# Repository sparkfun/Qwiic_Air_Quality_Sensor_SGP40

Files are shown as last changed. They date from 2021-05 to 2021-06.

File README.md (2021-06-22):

SparkFun Air Quality Sensor Breakout - SGP40 (Qwiic)
========================================

SparkFun Air Quality Sensor Breakout - SGP40 (Qwiic) (SEN-18345) (https://www.sparkfun.com/products/18345)

[*SparkFun Air Quality Sensor Breakout - SGP40 (Qwiic) (SEN-18345)*](https://www.sparkfun.com/products/18345)

The SGP40 is a digital gas sensor designed for easy integration into air purifiers or demand-controlled ventilation systems.
Sensirion’s CMOSens® technology offers a complete, easy to use sensor system on a single chip featuring a digital
I<sup>2</sup>C interface and a temperature controlled micro hotplate, providing a humidity compensated VOC based indoor air quality signal.
The output signal can be directly processed by Sensirion’s powerful VOC Algorithm to translate the raw signal into a VOC Index as a robust
measure for indoor air quality. The VOC Algorithm automatically adapts to the environment the sensor is exposed to. Both sensing element and
VOC Algorithm feature an unmatched robustness against contaminating gases present in real world applications enabling a unique long term
stability as well as low drift and device to device variation.

Repository Contents
-------------------
* **/Documents** - datasheets etc.
* **/Hardware** - Eagle design files (.brd, .sch)

Documentation
--------------
* **[SGP40 Arduino Library](https://github.com/sparkfun/SparkFun_SGP40_Arduino_Library)** - Arduino library for the SparkFun Air Quality Sensor - SGP40.
* **[Hookup Guide](https://learn.sparkfun.com/tutorials/air-quality-sensor---sgp40-qwiic-hookup-guide)** - Basic hookup guide for the SparkFun Air Quality Sensor - SGP40.

Product Versions
----------------
* [SEN-18345](https://www.sparkfun.com/products/18345) - Initial SparkFun release.
* [SPX-17729](https://www.sparkfun.com/products/17729) - Original SparkX Release.

License Information
-------------------

This product is _**open source**_!

Please review the LICENSE.md file for license information.

If you have any questions or concerns on licensing, please contact technical support on our [SparkFun forums](https://forum.sparkfun.com/viewforum.php?f=152).

Distributed as-is; no warranty is given.

- Your friends at SparkFun.

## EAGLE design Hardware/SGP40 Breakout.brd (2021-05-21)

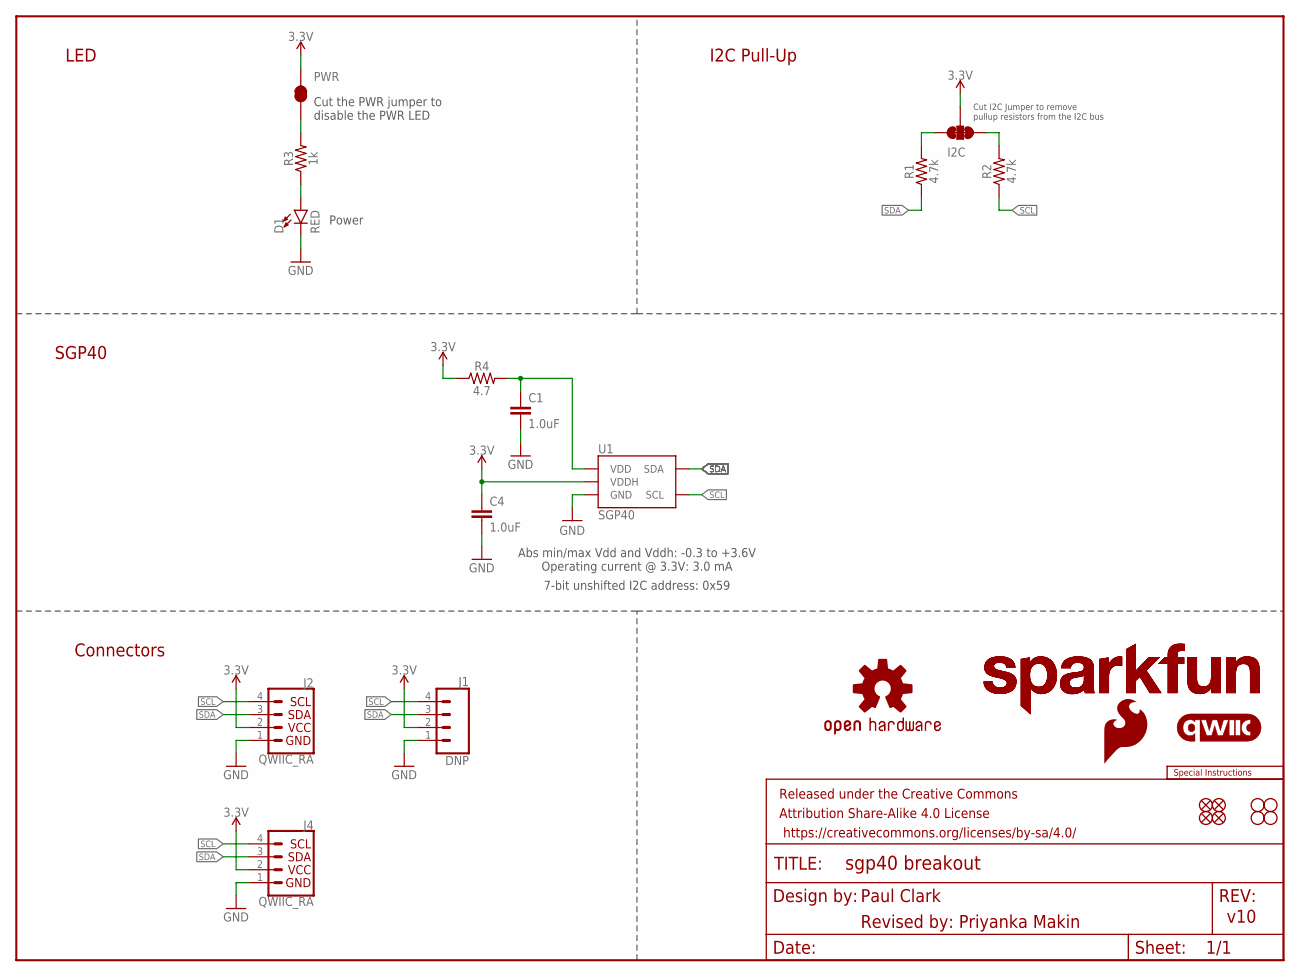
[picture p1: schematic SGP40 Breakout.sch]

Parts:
C1, C4: 1.0uF; 0603
D1: RED; LED-0603
FRAME1: FRAME-LETTER; CREATIVE_COMMONS
I2C: JUMPER-SMT_3_2-NC_TRACE_SILK; SMT-JUMPER_3_2-NC_TRACE_SILK
J1: DNP; 1X04_NO_SILK
J2, J4: QWIIC_RA; JST04_1MM_RA
JP1, JP2, JP5, JP6: FIDUCIAL0.2MM; FIDUCIAL-0.2MM
JP3, JP4, JP7, JP8: STAND-OFF
LOGO1: SPECIAL_INSTRUCTIONS-ORDERING; ORDERING_INSTRUCTIONS
LOGO2: QWIIC_LOGO_5MM; QWIIC_5MM
LOGO3, LOGO6: SFE_LOGO_NAME.1_INCH; SFE_LOGO_NAME_.1
LOGO4: SFE_LOGO_FLAME.1_INCH; SFE_LOGO_FLAME_.1
LOGO5: OSHW-LOGOS; OSHW-LOGO-S
PWR: JUMPER-SMT_2_NC_TRACE_SILK; SMT-JUMPER_2_NC_TRACE_SILK
R1, R2: 4.7k; 0603
R3: 1k; 0603
R4: 4.7; 0603
U1: SGP40

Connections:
3.3V: C4.1, I2C.2, J1.2, J2.2, J4.2, PWR.2, R4.1, U1.5 (VDDH)
GND: C1.2, C4.2, D1.C, J1.1, J2.1, J4.1, U1.2 (GND), U1.4 (GND), U1.DIEPAD (GND)
unnamed: PWR.1, R3.2
unnamed: I2C.3, R1.2
unnamed: D1.A, R3.1
unnamed: I2C.1, R2.2
unnamed: C1.1, R4.2, U1.1 (VDD)
SCL: J1.4, J2.4, J4.4, R2.1, U1.6 (SCL)
SDA: J1.3, J2.3, J4.3, R1.1, U1.3 (SDA)

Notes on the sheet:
Paul Clark
v10
7-bit unshifted I2C address: 0x59
Power
I2C Pull-Up
SGP40
Connectors
Cut the PWR jumper to disable the PWR LED
Cut I2C Jumper to remove pullup resistors from the I2C bus
LED
Revised by: Priyanka Makin
Abs min/max Vdd and Vddh: -0.3 to +3.6V Operating current @ 3.3V: 3.0 mA

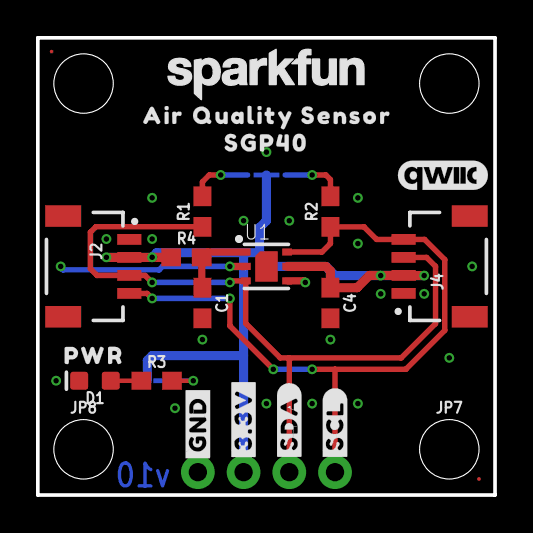
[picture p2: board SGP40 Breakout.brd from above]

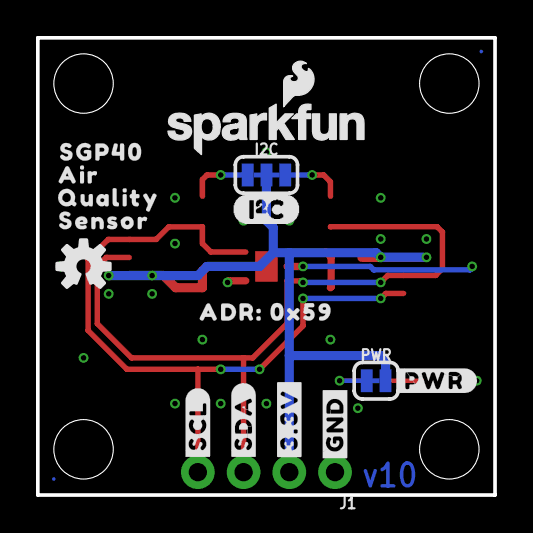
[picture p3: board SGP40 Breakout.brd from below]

Board: 2 copper layers, 25.4 x 25.4 mm, 48 parts (19 on the bottom side), 9 nets.

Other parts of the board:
U$1, U$33: #GND#0
U$2, U$34: #3#3V#0
U$3, U$35: #SDA#0
U$4, U$36: #SCL#0
U$5: PWR0
U$6: #PWR#0
U$15: I2C
U$19, U$20: SGP400
U$23, U$24: AIR0
U$25, U$28: QUALITY0
U$29, U$30: SENSOR0
U$31: ADR#_0X590

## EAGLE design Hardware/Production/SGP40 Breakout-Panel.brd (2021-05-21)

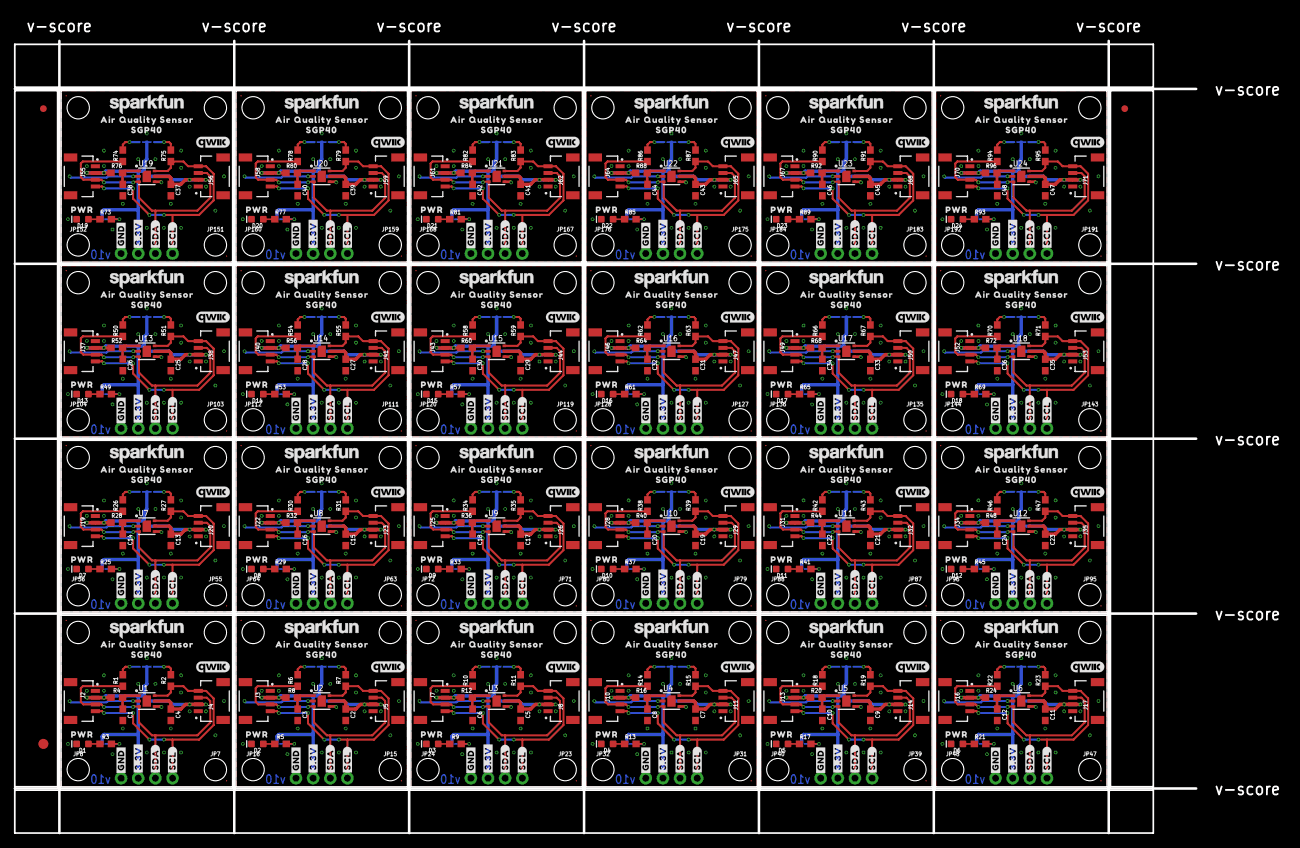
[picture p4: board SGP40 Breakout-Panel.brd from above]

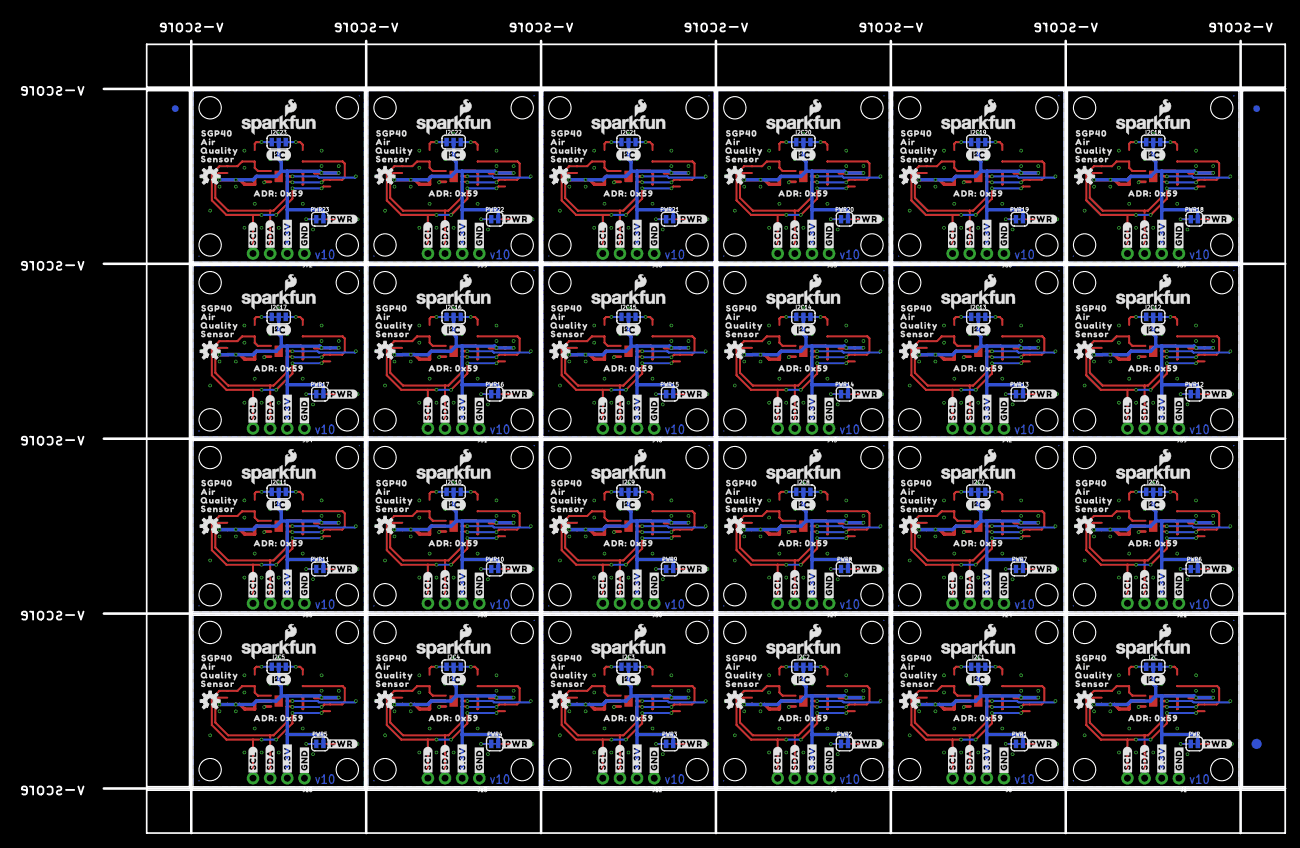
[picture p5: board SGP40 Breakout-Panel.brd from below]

Board: 2 copper layers, 175.0 x 117.3 mm, 1110 parts (459 on the bottom side), 216 nets.

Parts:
C1, C2, C3, C4, C5, C6, C7, C8, C9, C10, C11, C12, C13, C14, C15, C16, C17, C18, C19, C20, C21, C22, C23, C24, C25, C26, C27, C28, C29, C30, C31, C32, C33, C34, C35, C36, C37, C38, C39, C40, C41, C42, C43, C44, C45, C46, C47, C48: 1.0uF; 0603
D1, D2, D3, D4, D5, D6, D7, D8, D9, D10, D11, D12, D13, D14, D15, D16, D17, D18, D19, D20, D21, D22, D23, D24: RED; LED-0603
E$1, E$2, E$3, E$4: FIDUCIAL-1X2
E$5, E$6: FIDUCIAL-1.5X3
I2C, I2C1, I2C2, I2C3, I2C4, I2C5, I2C6, I2C7, I2C8, I2C9, I2C10, I2C11, I2C12, I2C13, I2C14, I2C15, I2C16, I2C17, I2C18, I2C19, I2C20, I2C21, I2C22, I2C23: JUMPER-SMT_3_2-NC_TRACE_SILK; SMT-JUMPER_3_2-NC_TRACE_SILK
J1, J6, J9, J12, J15, J18, J21, J24, J27, J30, J33, J36, J39, J42, J45, J48, J51, J54, J57, J60, J63, J66, J69, J72: DNP; 1X04_NO_SILK
J2, J3, J4, J5, J7, J8, J10, J11, J13, J14, J16, J17, J19, J20, J22, J23, J25, J26, J28, J29, J31, J32, J34, J35, J37, J38, J40, J41, J43, J44, J46, J47, J49, J50, J52, J53, J55, J56, J58, J59, J61, J62, J64, J65, J67, J68, J70, J71: QWIIC_RA; JST04_1MM_RA
JP1, JP2, JP5, JP6, JP11, JP12, JP13, JP14, JP19, JP20, JP21, JP22, JP27, JP28, JP29, JP30, JP35, JP36, JP37, JP38, JP43, JP44, JP45, JP46, JP51, JP52, JP53, JP54, JP59, JP60, JP61, JP62, JP67, JP68, JP69, JP70, JP75, JP76, JP77, JP78, JP83, JP84, JP85, JP86, JP91, JP92, JP93, JP94, JP99, JP100, JP101, JP102, JP107, JP108, JP109, JP110, JP115, JP116, JP117, JP118, JP123, JP124, JP125, JP126, JP131, JP132, JP133, JP134, JP139, JP140, JP141, JP142, JP147, JP148, JP149, JP150, JP155, JP156, JP157, JP158, JP163, JP164, JP165, JP166, JP171, JP172, JP173, JP174, JP179, JP180, JP181, JP182, JP187, JP188, JP189, JP190: FIDUCIAL0.2MM; FIDUCIAL-0.2MM
JP3, JP4, JP7, JP8, JP9, JP10, JP15, JP16, JP17, JP18, JP23, JP24, JP25, JP26, JP31, JP32, JP33, JP34, JP39, JP40, JP41, JP42, JP47, JP48, JP49, JP50, JP55, JP56, JP57, JP58, JP63, JP64, JP65, JP66, JP71, JP72, JP73, JP74, JP79, JP80, JP81, JP82, JP87, JP88, JP89, JP90, JP95, JP96, JP97, JP98, JP103, JP104, JP105, JP106, JP111, JP112, JP113, JP114, JP119, JP120, JP121, JP122, JP127, JP128, JP129, JP130, JP135, JP136, JP137, JP138, JP143, JP144, JP145, JP146, JP151, JP152, JP153, JP154, JP159, JP160, JP161, JP162, JP167, JP168, JP169, JP170, JP175, JP176, JP177, JP178, JP183, JP184, JP185, JP186, JP191, JP192: STAND-OFF
LOGO1, LOGO5, LOGO11, LOGO16, LOGO21, LOGO26, LOGO31, LOGO36, LOGO41, LOGO46, LOGO51, LOGO56, LOGO61, LOGO66, LOGO71, LOGO76, LOGO81, LOGO86, LOGO91, LOGO96, LOGO101, LOGO106, LOGO111, LOGO116: OSHW-LOGOS; OSHW-LOGO-S
LOGO2, LOGO7, LOGO12, LOGO17, LOGO22, LOGO27, LOGO32, LOGO37, LOGO42, LOGO47, LOGO52, LOGO57, LOGO62, LOGO67, LOGO72, LOGO77, LOGO82, LOGO87, LOGO92, LOGO97, LOGO102, LOGO107, LOGO112, LOGO117: QWIIC_LOGO_5MM; QWIIC_5MM
LOGO3, LOGO6, LOGO8, LOGO10, LOGO13, LOGO15, LOGO18, LOGO20, LOGO23, LOGO25, LOGO28, LOGO30, LOGO33, LOGO35, LOGO38, LOGO40, LOGO43, LOGO45, LOGO48, LOGO50, LOGO53, LOGO55, LOGO58, LOGO60, LOGO63, LOGO65, LOGO68, LOGO70, LOGO73, LOGO75, LOGO78, LOGO80, LOGO83, LOGO85, LOGO88, LOGO90, LOGO93, LOGO95, LOGO98, LOGO100, LOGO103, LOGO105, LOGO108, LOGO110, LOGO113, LOGO115, LOGO118, LOGO120: SFE_LOGO_NAME.1_INCH; SFE_LOGO_NAME_.1
LOGO4, LOGO9, LOGO14, LOGO19, LOGO24, LOGO29, LOGO34, LOGO39, LOGO44, LOGO49, LOGO54, LOGO59, LOGO64, LOGO69, LOGO74, LOGO79, LOGO84, LOGO89, LOGO94, LOGO99, LOGO104, LOGO109, LOGO114, LOGO119: SFE_LOGO_FLAME.1_INCH; SFE_LOGO_FLAME_.1
PWR, PWR1, PWR2, PWR3, PWR4, PWR5, PWR6, PWR7, PWR8, PWR9, PWR10, PWR11, PWR12, PWR13, PWR14, PWR15, PWR16, PWR17, PWR18, PWR19, PWR20, PWR21, PWR22, PWR23: JUMPER-SMT_2_NC_TRACE_SILK; SMT-JUMPER_2_NC_TRACE_SILK
R1, R2, R6, R7, R10, R11, R14, R15, R18, R19, R22, R23, R26, R27, R30, R31, R34, R35, R38, R39, R42, R43, R46, R47, R50, R51, R54, R55, R58, R59, R62, R63, R66, R67, R70, R71, R74, R75, R78, R79, R82, R83, R86, R87, R90, R91, R94, R95: 4.7k; 0603
R3, R5, R9, R13, R17, R21, R25, R29, R33, R37, R41, R45, R49, R53, R57, R61, R65, R69, R73, R77, R81, R85, R89, R93: 1k; 0603
R4, R8, R12, R16, R20, R24, R28, R32, R36, R40, R44, R48, R52, R56, R60, R64, R68, R72, R76, R80, R84, R88, R92, R96: 4.7; 0603
U1, U2, U3, U4, U5, U6, U7, U8, U9, U10, U11, U12, U13, U14, U15, U16, U17, U18, U19, U20, U21, U22, U23, U24: SGP40
U$1, U$18, U$27, U$33, U$51, U$55, U$71, U$75, U$91, U$95, U$111, U$115, U$131, U$135, U$151, U$155, U$171, U$175, U$191, U$195, U$211, U$215, U$231, U$235, U$251, U$255, U$271, U$275, U$291, U$295, U$311, U$315, U$331, U$335, U$351, U$355, U$371, U$375, U$391, U$395, U$411, U$415, U$431, U$435, U$451, U$455, U$471, U$475: #GND#0
U$2, U$21, U$32, U$34, U$52, U$56, U$72, U$76, U$92, U$96, U$112, U$116, U$132, U$136, U$152, U$156, U$172, U$176, U$192, U$196, U$212, U$216, U$232, U$236, U$252, U$256, U$272, U$276, U$292, U$296, U$312, U$316, U$332, U$336, U$352, U$356, U$372, U$376, U$392, U$396, U$412, U$416, U$432, U$436, U$452, U$456, U$472, U$476: #3#3V#0
U$3, U$22, U$35, U$37, U$53, U$57, U$73, U$77, U$93, U$97, U$113, U$117, U$133, U$137, U$153, U$157, U$173, U$177, U$193, U$197, U$213, U$217, U$233, U$237, U$253, U$257, U$273, U$277, U$293, U$297, U$313, U$317, U$333, U$337, U$353, U$357, U$373, U$377, U$393, U$397, U$413, U$417, U$433, U$437, U$453, U$457, U$473, U$477: #SDA#0
U$4, U$26, U$36, U$38, U$54, U$58, U$74, U$78, U$94, U$98, U$114, U$118, U$134, U$138, U$154, U$158, U$174, U$178, U$194, U$198, U$214, U$218, U$234, U$238, U$254, U$258, U$274, U$278, U$294, U$298, U$314, U$318, U$334, U$338, U$354, U$358, U$374, U$378, U$394, U$398, U$414, U$418, U$434, U$438, U$454, U$458, U$474, U$478: #SCL#0
U$5, U$39, U$59, U$79, U$99, U$119, U$139, U$159, U$179, U$199, U$219, U$239, U$259, U$279, U$299, U$319, U$339, U$359, U$379, U$399, U$419, U$439, U$459, U$479: PWR0
U$6, U$40, U$60, U$80, U$100, U$120, U$140, U$160, U$180, U$200, U$220, U$240, U$260, U$280, U$300, U$320, U$340, U$360, U$380, U$400, U$420, U$440, U$460, U$480: #PWR#0
U$7, U$15, U$41, U$61, U$81, U$101, U$121, U$141, U$161, U$181, U$201, U$221, U$241, U$261, U$281, U$301, U$321, U$341, U$361, U$381, U$401, U$421, U$441, U$461: I2C
U$8, U$9, U$19, U$20, U$42, U$43, U$62, U$63, U$82, U$83, U$102, U$103, U$122, U$123, U$142, U$143, U$162, U$163, U$182, U$183, U$202, U$203, U$222, U$223, U$242, U$243, U$262, U$263, U$282, U$283, U$302, U$303, U$322, U$323, U$342, U$343, U$362, U$363, U$382, U$383, U$402, U$403, U$422, U$423, U$442, U$443, U$462, U$463: SGP400
U$10, U$11, U$23, U$24, U$44, U$45, U$64, U$65, U$84, U$85, U$104, U$105, U$124, U$125, U$144, U$145, U$164, U$165, U$184, U$185, U$204, U$205, U$224, U$225, U$244, U$245, U$264, U$265, U$284, U$285, U$304, U$305, U$324, U$325, U$344, U$345, U$364, U$365, U$384, U$385, U$404, U$405, U$424, U$425, U$444, U$445, U$464, U$465: AIR0
U$12, U$13, U$25, U$28, U$46, U$47, U$66, U$67, U$86, U$87, U$106, U$107, U$126, U$127, U$146, U$147, U$166, U$167, U$186, U$187, U$206, U$207, U$226, U$227, U$246, U$247, U$266, U$267, U$286, U$287, U$306, U$307, U$326, U$327, U$346, U$347, U$366, U$367, U$386, U$387, U$406, U$407, U$426, U$427, U$446, U$447, U$466, U$467: QUALITY0
U$14, U$16, U$29, U$30, U$48, U$49, U$68, U$69, U$88, U$89, U$108, U$109, U$128, U$129, U$148, U$149, U$168, U$169, U$188, U$189, U$208, U$209, U$228, U$229, U$248, U$249, U$268, U$269, U$288, U$289, U$308, U$309, U$328, U$329, U$348, U$349, U$368, U$369, U$388, U$389, U$408, U$409, U$428, U$429, U$448, U$449, U$468, U$469: SENSOR0
U$17, U$31, U$50, U$70, U$90, U$110, U$130, U$150, U$170, U$190, U$210, U$230, U$250, U$270, U$290, U$310, U$330, U$350, U$370, U$390, U$410, U$430, U$450, U$470: ADR#_0X590

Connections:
3.3V: C4.1, I2C.2, J1.2, J2.2, J4.2, PWR.2, R4.1, U1.5
3.3V1: C2.1, I2C1.2, J3.2, J5.2, J6.2, PWR1.2, R8.1, U2.5
3.3V2: C5.1, I2C2.2, J7.2, J8.2, J9.2, PWR2.2, R12.1, U3.5
3.3V3: C7.1, I2C3.2, J10.2, J11.2, J12.2, PWR3.2, R16.1, U4.5
3.3V4: C9.1, I2C4.2, J13.2, J14.2, J15.2, PWR4.2, R20.1, U5.5
3.3V5: C11.1, I2C5.2, J16.2, J17.2, J18.2, PWR5.2, R24.1, U6.5
3.3V6: C13.1, I2C6.2, J19.2, J20.2, J21.2, PWR6.2, R28.1, U7.5
3.3V7: C15.1, I2C7.2, J22.2, J23.2, J24.2, PWR7.2, R32.1, U8.5
3.3V8: C17.1, I2C8.2, J25.2, J26.2, J27.2, PWR8.2, R36.1, U9.5
3.3V9: C19.1, I2C9.2, J28.2, J29.2, J30.2, PWR9.2, R40.1, U10.5
3.3V10: C21.1, I2C10.2, J31.2, J32.2, J33.2, PWR10.2, R44.1, U11.5
3.3V11: C23.1, I2C11.2, J34.2, J35.2, J36.2, PWR11.2, R48.1, U12.5
3.3V12: C25.1, I2C12.2, J37.2, J38.2, J39.2, PWR12.2, R52.1, U13.5
3.3V13: C27.1, I2C13.2, J40.2, J41.2, J42.2, PWR13.2, R56.1, U14.5
3.3V14: C29.1, I2C14.2, J43.2, J44.2, J45.2, PWR14.2, R60.1, U15.5
3.3V15: C31.1, I2C15.2, J46.2, J47.2, J48.2, PWR15.2, R64.1, U16.5
3.3V16: C33.1, I2C16.2, J49.2, J50.2, J51.2, PWR16.2, R68.1, U17.5
3.3V17: C35.1, I2C17.2, J52.2, J53.2, J54.2, PWR17.2, R72.1, U18.5
3.3V18: C37.1, I2C18.2, J55.2, J56.2, J57.2, PWR18.2, R76.1, U19.5
3.3V19: C39.1, I2C19.2, J58.2, J59.2, J60.2, PWR19.2, R80.1, U20.5
3.3V20: C41.1, I2C20.2, J61.2, J62.2, J63.2, PWR20.2, R84.1, U21.5
3.3V21: C43.1, I2C21.2, J64.2, J65.2, J66.2, PWR21.2, R88.1, U22.5
3.3V22: C45.1, I2C22.2, J67.2, J68.2, J69.2, PWR22.2, R92.1, U23.5
3.3V23: C47.1, I2C23.2, J70.2, J71.2, J72.2, PWR23.2, R96.1, U24.5
GND: C1.2, C4.2, D1.C, J1.1, J2.1, J4.1, U1.2, U1.4, U1.DIEPAD
GND1: C2.2, C3.2, D2.C, J3.1, J5.1, J6.1, U2.2, U2.4, U2.DIEPAD
GND2: C5.2, C6.2, D3.C, J7.1, J8.1, J9.1, U3.2, U3.4, U3.DIEPAD
GND3: C7.2, C8.2, D4.C, J10.1, J11.1, J12.1, U4.2, U4.4, U4.DIEPAD
GND4: C9.2, C10.2, D5.C, J13.1, J14.1, J15.1, U5.2, U5.4, U5.DIEPAD
GND5: C11.2, C12.2, D6.C, J16.1, J17.1, J18.1, U6.2, U6.4, U6.DIEPAD
GND6: C13.2, C14.2, D7.C, J19.1, J20.1, J21.1, U7.2, U7.4, U7.DIEPAD
GND7: C15.2, C16.2, D8.C, J22.1, J23.1, J24.1, U8.2, U8.4, U8.DIEPAD
GND8: C17.2, C18.2, D9.C, J25.1, J26.1, J27.1, U9.2, U9.4, U9.DIEPAD
GND9: C19.2, C20.2, D10.C, J28.1, J29.1, J30.1, U10.2, U10.4, U10.DIEPAD
GND10: C21.2, C22.2, D11.C, J31.1, J32.1, J33.1, U11.2, U11.4, U11.DIEPAD
GND11: C23.2, C24.2, D12.C, J34.1, J35.1, J36.1, U12.2, U12.4, U12.DIEPAD
GND12: C25.2, C26.2, D13.C, J37.1, J38.1, J39.1, U13.2, U13.4, U13.DIEPAD
GND13: C27.2, C28.2, D14.C, J40.1, J41.1, J42.1, U14.2, U14.4, U14.DIEPAD
GND14: C29.2, C30.2, D15.C, J43.1, J44.1, J45.1, U15.2, U15.4, U15.DIEPAD
GND15: C31.2, C32.2, D16.C, J46.1, J47.1, J48.1, U16.2, U16.4, U16.DIEPAD
GND16: C33.2, C34.2, D17.C, J49.1, J50.1, J51.1, U17.2, U17.4, U17.DIEPAD
GND17: C35.2, C36.2, D18.C, J52.1, J53.1, J54.1, U18.2, U18.4, U18.DIEPAD
GND18: C37.2, C38.2, D19.C, J55.1, J56.1, J57.1, U19.2, U19.4, U19.DIEPAD
GND19: C39.2, C40.2, D20.C, J58.1, J59.1, J60.1, U20.2, U20.4, U20.DIEPAD
GND20: C41.2, C42.2, D21.C, J61.1, J62.1, J63.1, U21.2, U21.4, U21.DIEPAD
GND21: C43.2, C44.2, D22.C, J64.1, J65.1, J66.1, U22.2, U22.4, U22.DIEPAD
GND22: C45.2, C46.2, D23.C, J67.1, J68.1, J69.1, U23.2, U23.4, U23.DIEPAD
GND23: C47.2, C48.2, D24.C, J70.1, J71.1, J72.1, U24.2, U24.4, U24.DIEPAD
unnamed: PWR.1, R3.2
unnamed: I2C.3, R1.2
unnamed: D1.A, R3.1
unnamed: I2C.1, R2.2
unnamed: C1.1, R4.2, U1.1
unnamed: D2.A, R5.1
unnamed: PWR1.1, R5.2
unnamed: I2C1.3, R6.2
unnamed: I2C1.1, R7.2
unnamed: C3.1, R8.2, U2.1
unnamed: D3.A, R9.1
unnamed: PWR2.1, R9.2
unnamed: I2C2.3, R10.2
unnamed: I2C2.1, R11.2
unnamed: C6.1, R12.2, U3.1
unnamed: D4.A, R13.1
unnamed: PWR3.1, R13.2
unnamed: I2C3.3, R14.2
unnamed: I2C3.1, R15.2
unnamed: C8.1, R16.2, U4.1
unnamed: D5.A, R17.1
unnamed: PWR4.1, R17.2
unnamed: I2C4.3, R18.2
unnamed: I2C4.1, R19.2
unnamed: C10.1, R20.2, U5.1
unnamed: D6.A, R21.1
unnamed: PWR5.1, R21.2
unnamed: I2C5.3, R22.2
unnamed: I2C5.1, R23.2
unnamed: C12.1, R24.2, U6.1
unnamed: D7.A, R25.1
unnamed: PWR6.1, R25.2
unnamed: I2C6.3, R26.2
unnamed: I2C6.1, R27.2
unnamed: C14.1, R28.2, U7.1
unnamed: D8.A, R29.1
unnamed: PWR7.1, R29.2
unnamed: I2C7.3, R30.2
unnamed: I2C7.1, R31.2
unnamed: C16.1, R32.2, U8.1
unnamed: D9.A, R33.1
unnamed: PWR8.1, R33.2
unnamed: I2C8.3, R34.2
unnamed: I2C8.1, R35.2
unnamed: C18.1, R36.2, U9.1
unnamed: D10.A, R37.1
unnamed: PWR9.1, R37.2
unnamed: I2C9.3, R38.2
unnamed: I2C9.1, R39.2
unnamed: C20.1, R40.2, U10.1
unnamed: D11.A, R41.1
unnamed: PWR10.1, R41.2
unnamed: I2C10.3, R42.2
unnamed: I2C10.1, R43.2
unnamed: C22.1, R44.2, U11.1
unnamed: D12.A, R45.1
unnamed: PWR11.1, R45.2
unnamed: I2C11.3, R46.2
unnamed: I2C11.1, R47.2
unnamed: C24.1, R48.2, U12.1
unnamed: D13.A, R49.1
unnamed: PWR12.1, R49.2
unnamed: I2C12.3, R50.2
unnamed: I2C12.1, R51.2
unnamed: C26.1, R52.2, U13.1
unnamed: D14.A, R53.1
unnamed: PWR13.1, R53.2
unnamed: I2C13.3, R54.2
unnamed: I2C13.1, R55.2
unnamed: C28.1, R56.2, U14.1
unnamed: D15.A, R57.1
unnamed: PWR14.1, R57.2
unnamed: I2C14.3, R58.2
unnamed: I2C14.1, R59.2
unnamed: C30.1, R60.2, U15.1
unnamed: D16.A, R61.1
unnamed: PWR15.1, R61.2
unnamed: I2C15.3, R62.2
unnamed: I2C15.1, R63.2
unnamed: C32.1, R64.2, U16.1
unnamed: D17.A, R65.1
unnamed: PWR16.1, R65.2
unnamed: I2C16.3, R66.2
unnamed: I2C16.1, R67.2
unnamed: C34.1, R68.2, U17.1
unnamed: D18.A, R69.1
unnamed: PWR17.1, R69.2
unnamed: I2C17.3, R70.2
unnamed: I2C17.1, R71.2
unnamed: C36.1, R72.2, U18.1
unnamed: D19.A, R73.1
unnamed: PWR18.1, R73.2
unnamed: I2C18.3, R74.2
unnamed: I2C18.1, R75.2
unnamed: C38.1, R76.2, U19.1
unnamed: D20.A, R77.1
unnamed: PWR19.1, R77.2
unnamed: I2C19.3, R78.2
unnamed: I2C19.1, R79.2
unnamed: C40.1, R80.2, U20.1
unnamed: D21.A, R81.1
unnamed: PWR20.1, R81.2
unnamed: I2C20.3, R82.2
unnamed: I2C20.1, R83.2
unnamed: C42.1, R84.2, U21.1
unnamed: D22.A, R85.1
unnamed: PWR21.1, R85.2
unnamed: I2C21.3, R86.2
unnamed: I2C21.1, R87.2
unnamed: C44.1, R88.2, U22.1
unnamed: D23.A, R89.1
unnamed: PWR22.1, R89.2
unnamed: I2C22.3, R90.2
unnamed: I2C22.1, R91.2
unnamed: C46.1, R92.2, U23.1
unnamed: D24.A, R93.1
unnamed: PWR23.1, R93.2
unnamed: I2C23.3, R94.2
unnamed: I2C23.1, R95.2
unnamed: C48.1, R96.2, U24.1
SCL: J1.4, J2.4, J4.4, R2.1, U1.6
SCL1: J3.4, J5.4, J6.4, R7.1, U2.6
SCL2: J7.4, J8.4, J9.4, R11.1, U3.6
SCL3: J10.4, J11.4, J12.4, R15.1, U4.6
SCL4: J13.4, J14.4, J15.4, R19.1, U5.6
SCL5: J16.4, J17.4, J18.4, R23.1, U6.6
SCL6: J19.4, J20.4, J21.4, R27.1, U7.6
SCL7: J22.4, J23.4, J24.4, R31.1, U8.6
SCL8: J25.4, J26.4, J27.4, R35.1, U9.6
SCL9: J28.4, J29.4, J30.4, R39.1, U10.6
SCL10: J31.4, J32.4, J33.4, R43.1, U11.6
SCL11: J34.4, J35.4, J36.4, R47.1, U12.6
SCL12: J37.4, J38.4, J39.4, R51.1, U13.6
SCL13: J40.4, J41.4, J42.4, R55.1, U14.6
SCL14: J43.4, J44.4, J45.4, R59.1, U15.6
SCL15: J46.4, J47.4, J48.4, R63.1, U16.6
SCL16: J49.4, J50.4, J51.4, R67.1, U17.6
SCL17: J52.4, J53.4, J54.4, R71.1, U18.6
SCL18: J55.4, J56.4, J57.4, R75.1, U19.6
SCL19: J58.4, J59.4, J60.4, R79.1, U20.6
SCL20: J61.4, J62.4, J63.4, R83.1, U21.6
SCL21: J64.4, J65.4, J66.4, R87.1, U22.6
SCL22: J67.4, J68.4, J69.4, R91.1, U23.6
SCL23: J70.4, J71.4, J72.4, R95.1, U24.6
SDA: J1.3, J2.3, J4.3, R1.1, U1.3
SDA1: J3.3, J5.3, J6.3, R6.1, U2.3
SDA2: J7.3, J8.3, J9.3, R10.1, U3.3
SDA3: J10.3, J11.3, J12.3, R14.1, U4.3
SDA4: J13.3, J14.3, J15.3, R18.1, U5.3
SDA5: J16.3, J17.3, J18.3, R22.1, U6.3
SDA6: J19.3, J20.3, J21.3, R26.1, U7.3
SDA7: J22.3, J23.3, J24.3, R30.1, U8.3
SDA8: J25.3, J26.3, J27.3, R34.1, U9.3
SDA9: J28.3, J29.3, J30.3, R38.1, U10.3
SDA10: J31.3, J32.3, J33.3, R42.1, U11.3
SDA11: J34.3, J35.3, J36.3, R46.1, U12.3
SDA12: J37.3, J38.3, J39.3, R50.1, U13.3
SDA13: J40.3, J41.3, J42.3, R54.1, U14.3
SDA14: J43.3, J44.3, J45.3, R58.1, U15.3
SDA15: J46.3, J47.3, J48.3, R62.1, U16.3
SDA16: J49.3, J50.3, J51.3, R66.1, U17.3
SDA17: J52.3, J53.3, J54.3, R70.1, U18.3
SDA18: J55.3, J56.3, J57.3, R74.1, U19.3
SDA19: J58.3, J59.3, J60.3, R78.1, U20.3
SDA20: J61.3, J62.3, J63.3, R82.1, U21.3
SDA21: J64.3, J65.3, J66.3, R86.1, U22.3
SDA22: J67.3, J68.3, J69.3, R90.1, U23.3
SDA23: J70.3, J71.3, J72.3, R94.1, U24.3

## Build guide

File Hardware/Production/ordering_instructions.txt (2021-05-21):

panel size, 169x117mm
PCB thickness, 1.6mm
number of layers, 2
soldermask color, Red
silkscreen color, White
oz copper, 1oz
finish, HASL lead free
stencils, top
pcs per panel, 24
min trace width, 0.2540mm / 0.0100in
min drill size, 0.3000mm / 0.0118in

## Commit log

2021-05-12 Initial commit with SparkX design files, readme, and datasheets
    [SGP40 Breakout.brd, SGP40 Breakout.sch]
2021-05-17 Update logos on board
    [SGP40 Breakout.brd, SGP40 Breakout.sch]
2021-05-18 Petes updates:
    Update version number in sch
    Added 2 more standoffs (moved power LED and jumper)
    Update value of qwiic connector in schematic
    Update legacy vector font
    Add qwiic connector and header measure
    Switched I2C pullup resistors to 4.7k
    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
    [SGP40 Breakout.brd, SGP40 Breakout.sch]
2021-05-18 Update silk
    LED label plain text
    Inverted bubbled for LED jumper
    Make SDA/SCL pin labels square on one side
    [SGP40 Breakout.brd]
2021-05-19 Design review updates
    SDA, SCL buzzard placement
    3.3V trace → 20
    Add operating current to sch
    [SGP40 Breakout.brd, SGP40 Breakout.sch]
2021-05-21 QC Double-check
    [SGP40 Breakout.brd, SGP40 Breakout.sch]

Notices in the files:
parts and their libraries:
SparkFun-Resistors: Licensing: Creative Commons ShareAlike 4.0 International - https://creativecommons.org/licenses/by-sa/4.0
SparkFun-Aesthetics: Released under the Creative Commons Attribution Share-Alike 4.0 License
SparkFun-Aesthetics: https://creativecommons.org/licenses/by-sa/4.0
